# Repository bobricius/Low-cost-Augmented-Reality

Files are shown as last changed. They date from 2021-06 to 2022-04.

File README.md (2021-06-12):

# Low-cost-Augmented-Reality
Optimized for use microcontrollers and SPI displays popular ST7789 1.3" IPS 240x240 FEEL LIKE IRON MAN !!!!!

Something like Iron man helmet but can drive with simple arduino
Raspberry pi zero, PICO and more

- Driven with simple SPI interface
- Helmet cost about 30$ displays 10$
- 2x SPI IPS display 240x240 ST7789
- Easy drive with #samd21 #rp2040 #raspberrypi #ESP32
- no complicated HDMI
- beautiful and clear image in all you view
- LOW power about 60mA including SAMD21 MCU
- parallel or separated (for 3D) display driving
- USB OTG

YOU CAN TYPE ON KEYBOARD AND DIRECT READ MESSAGES :D

-module also have prepared LoRa radio for sending/receiving messages and GPS

TODO:
- Adjustable distance between displays (flex cable or solder bridge)
- Test on Raspbery pi zero
- select nice 8pin cable/connector etc. USB-C with custom pinout

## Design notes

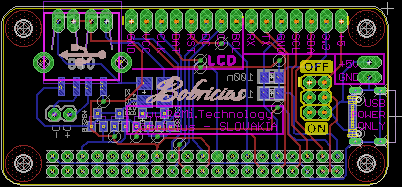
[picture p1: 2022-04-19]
pcb.png

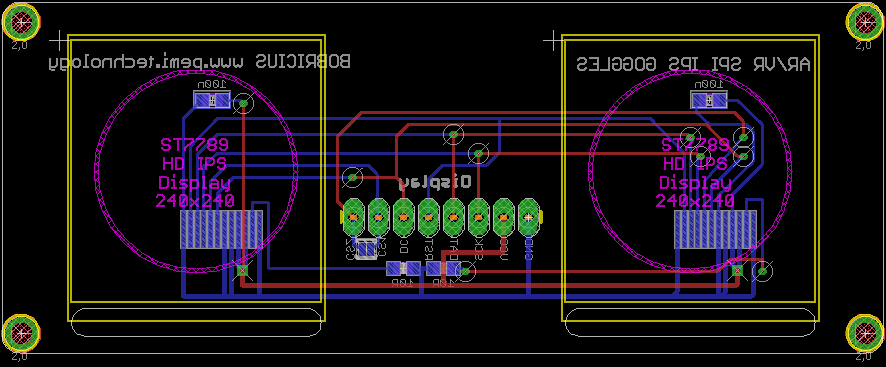
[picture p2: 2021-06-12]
board.png

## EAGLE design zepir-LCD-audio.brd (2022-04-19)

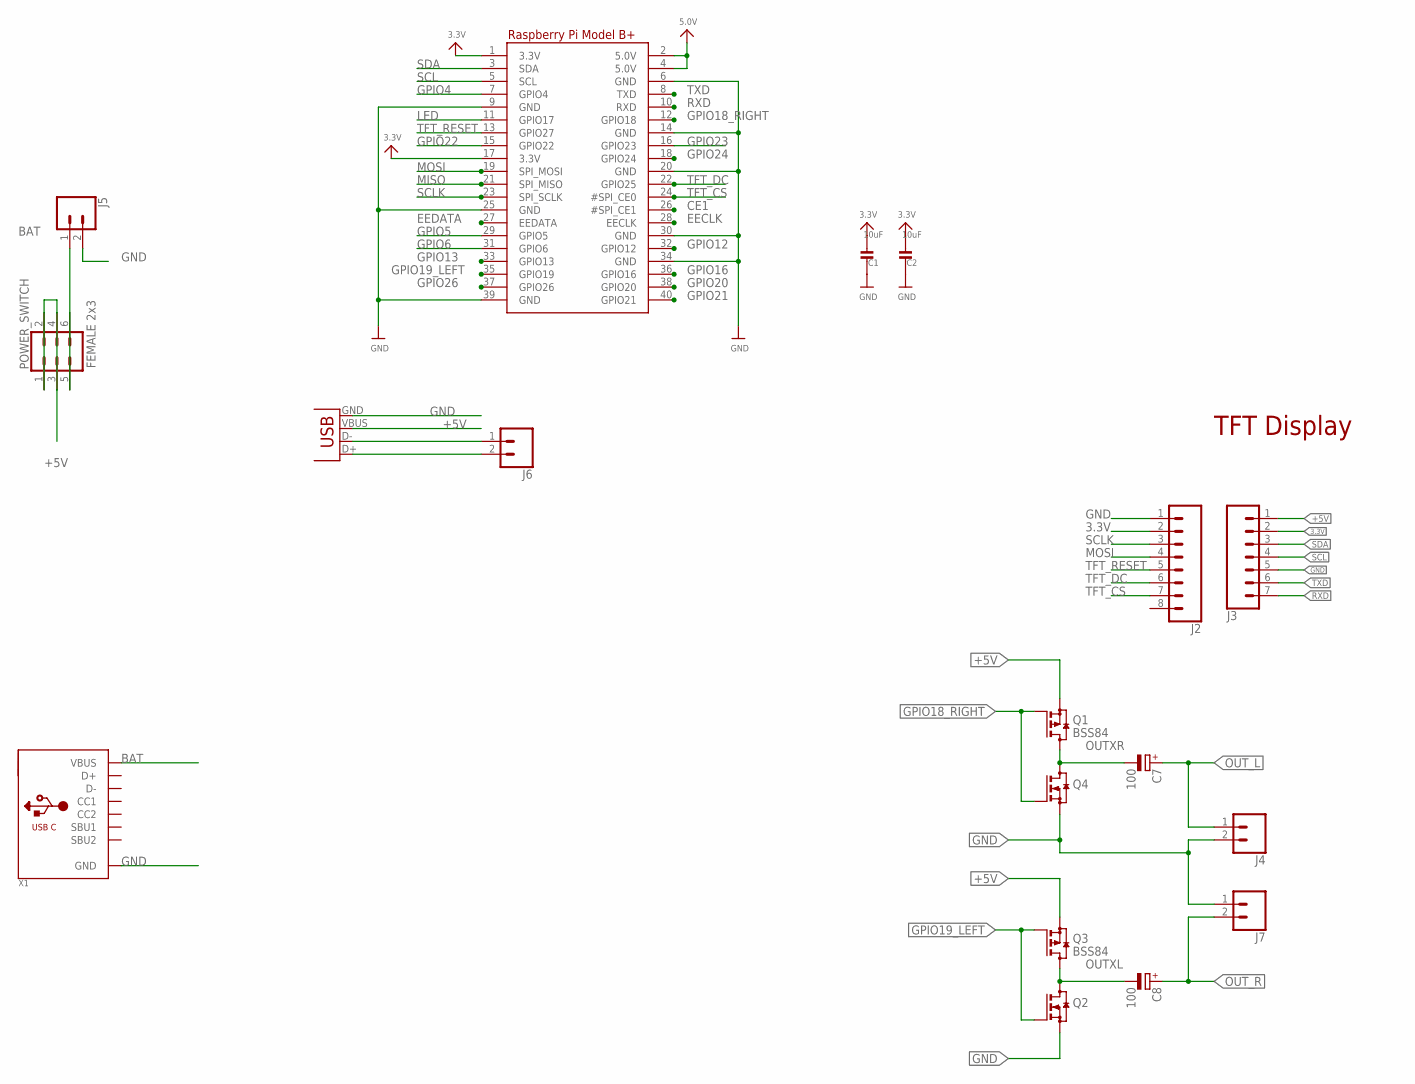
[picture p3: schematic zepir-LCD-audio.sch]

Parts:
C1, C2: 10uF; _1206
C7, C8: 100; B/3528-21R
J2: CONN_08LONGPADS; 1X08_LONGPADS
J3: CONN_07LONGPADS; 1X07_LONGPADS
J4, J5, J7: CONN_02PTH3; 1X02_LONGPADS
J6: CONN_02; 1X02
POWER_SWITCH: FEMALE 2x3; 2X3
Q1, Q3: BSS84; SOT23
Q2, Q4: BSS123; SOT23
RPI1: RASPBERRYPI_BPLUS_BONNETNODIM; PI_BONNET_NODIM
USBIN1: USB-A-SMD; USB-A-S-NOSILK-FEMALE
X1: USB_C; USB_C_CUSB31-CFM2AX-01-X

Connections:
3.3V: C1.2, C2.2, J2.2, J3.2, RPI1.1 (3.3V), RPI1.17 (3.3V)
+5V: J3.1, POWER_SWITCH.1, POWER_SWITCH.2, POWER_SWITCH.3, POWER_SWITCH.4, Q1.2 (S), Q3.2 (S), RPI1.2 (5.0V), RPI1.4 (5.0V), USBIN1.VBUS
BAT: J5.1, POWER_SWITCH.5, POWER_SWITCH.6, X1.A4B9 (VBUS), X1.B4A9 (VBUS)
CE1: RPI1.26 (#SPI_CE1)
DM: J6.1, USBIN1.D-
DP: J6.2, USBIN1.D+
EECLK: RPI1.28 (EECLK)
EEDATA: RPI1.27 (EEDATA)
GND: C1.1, C2.1, J2.1, J3.5, J4.2, J5.2, J7.1, Q2.2 (S), Q4.2 (S), RPI1.6 (GND), RPI1.9 (GND), RPI1.14 (GND), RPI1.20 (GND), RPI1.25 (GND), RPI1.30 (GND), RPI1.34 (GND), RPI1.39 (GND), USBIN1.GND, X1.A1B12 (GND), X1.B1A12 (GND)
GPIO4: RPI1.7 (GPIO4)
GPIO5: RPI1.29 (GPIO5)
GPIO6: RPI1.31 (GPIO6)
GPIO12: RPI1.32 (GPIO12)
GPIO13: RPI1.33 (GPIO13)
GPIO16: RPI1.36 (GPIO16)
GPIO18_RIGHT: Q1.1 (G), Q4.1 (G), RPI1.12 (GPIO18)
GPIO19_LEFT: Q2.1 (G), Q3.1 (G), RPI1.35 (GPIO19)
GPIO20: RPI1.38 (GPIO20)
GPIO21: RPI1.40 (GPIO21)
GPIO22: RPI1.15 (GPIO22)
GPIO23: RPI1.16 (GPIO23)
GPIO24: RPI1.18 (GPIO24)
GPIO26: RPI1.37 (GPIO26)
LED: RPI1.11 (GPIO17)
MISO: RPI1.21 (SPI_MISO)
MOSI: J2.4, RPI1.19 (SPI_MOSI)
OUTXL: C8.-, Q2.3 (D), Q3.3 (D)
OUTXR: C7.-, Q1.3 (D), Q4.3 (D)
OUT_L: C7.+, J4.1
OUT_R: C8.+, J7.2
RXD: J3.7, RPI1.10 (RXD)
SCL: J3.4, RPI1.5 (SCL)
SCLK: J2.3, RPI1.23 (SPI_SCLK)
SDA: J3.3, RPI1.3 (SDA)
TFT_CS: J2.7, RPI1.24 (#SPI_CE0)
TFT_DC: J2.6, RPI1.22 (GPIO25)
TFT_RESET: J2.5, RPI1.13 (GPIO27)
TXD: J3.6, RPI1.8 (TXD)

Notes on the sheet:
TFT Display

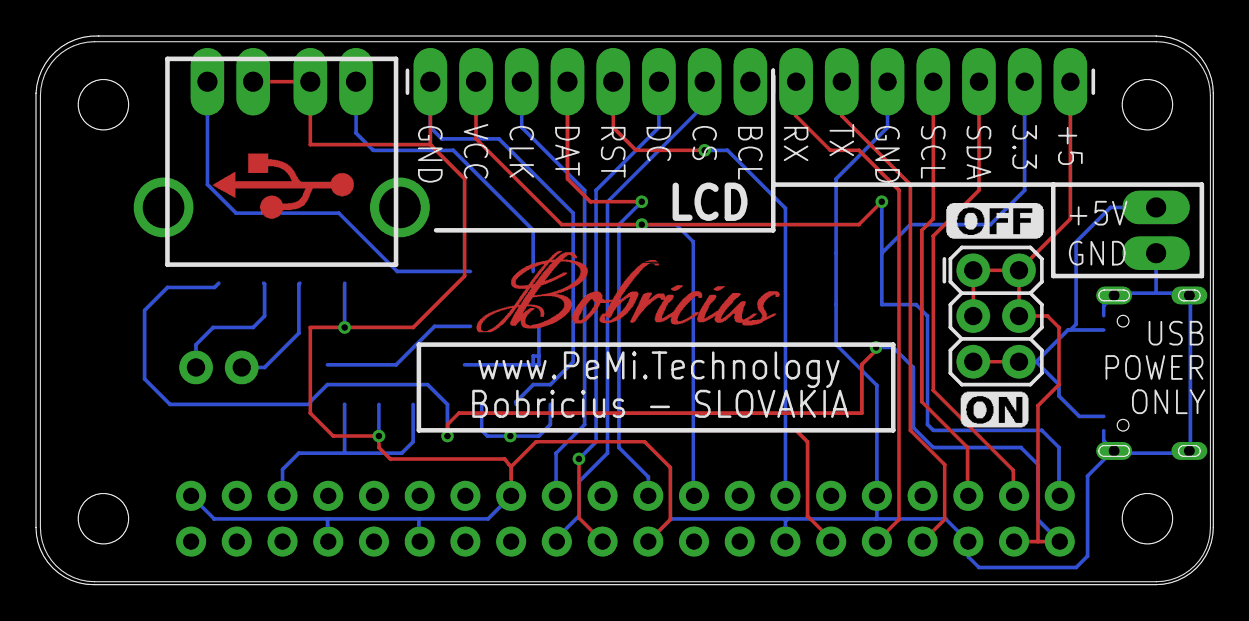
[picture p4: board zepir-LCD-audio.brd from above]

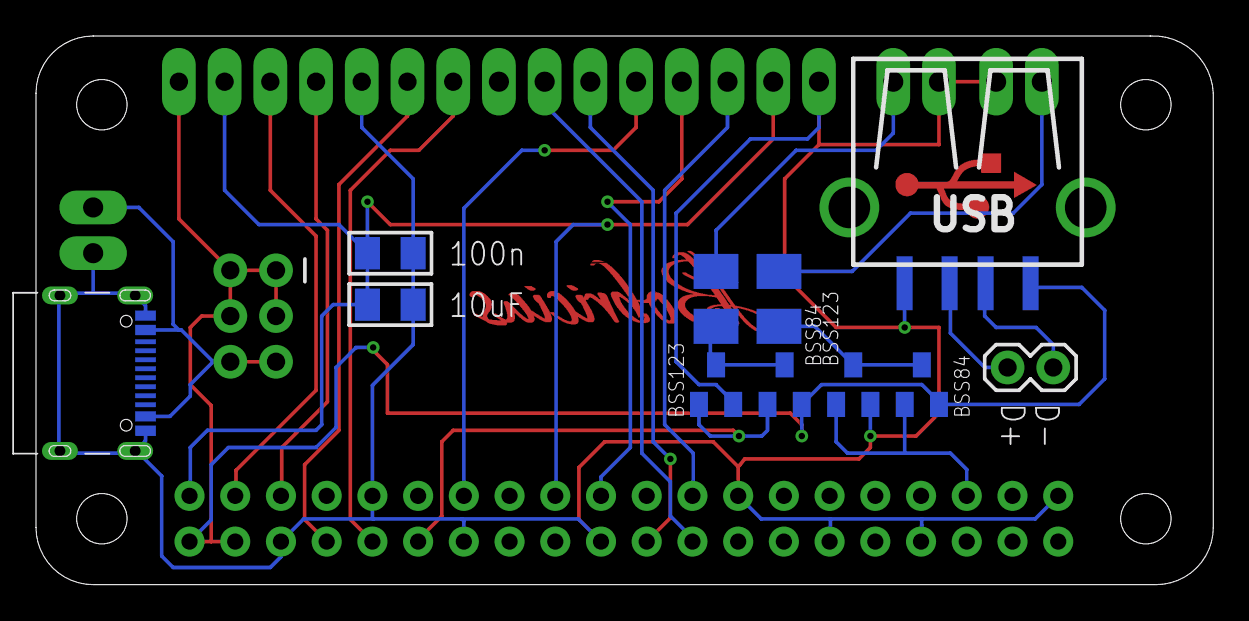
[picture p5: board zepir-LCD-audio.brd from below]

Board: 2 copper layers, 65.4 x 30.5 mm, 18 parts (11 on the bottom side), 21 nets.

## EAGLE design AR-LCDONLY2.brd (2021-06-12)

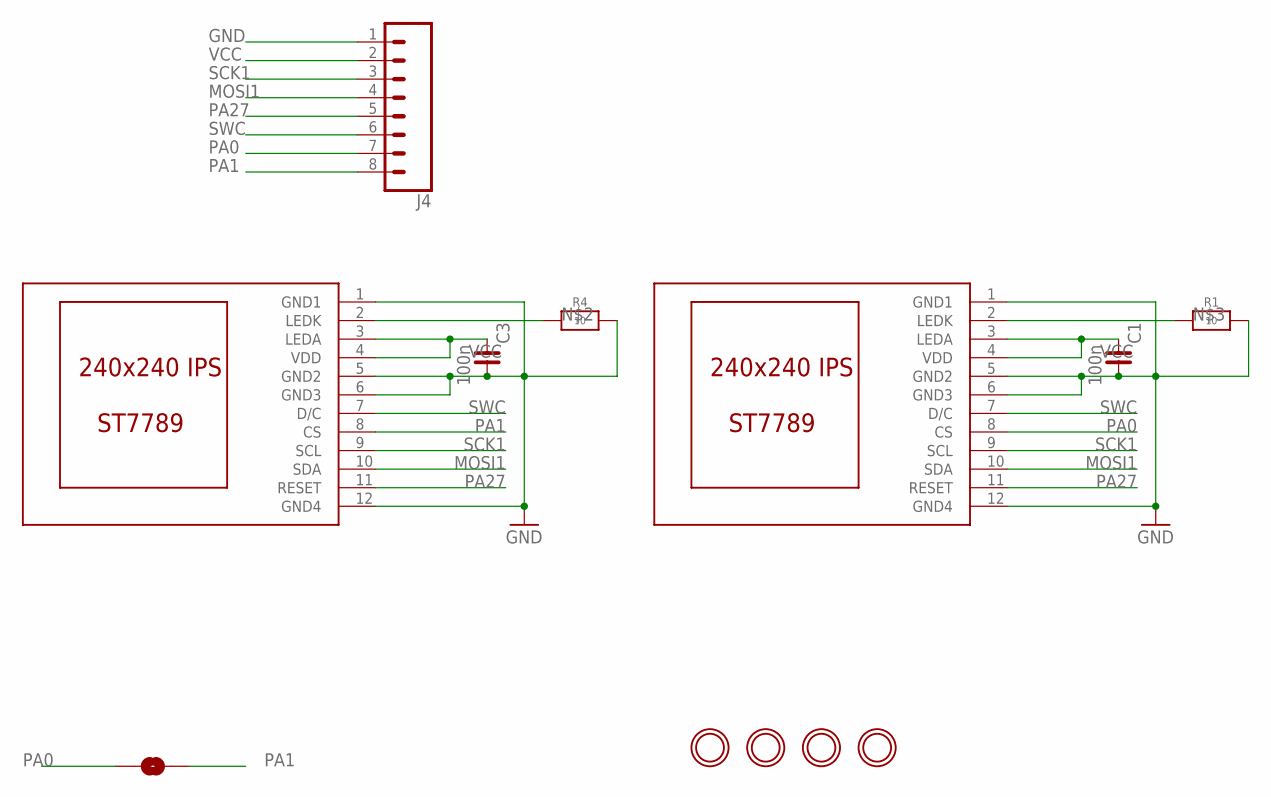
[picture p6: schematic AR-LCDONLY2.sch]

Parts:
C1, C3: 100n; C0805
J4: CONN_08LONGPADS; 1X08_LONGPADS
JUMPER1: SOLDERJUMPERNC2; SJ_2S-NOTRACE
R1, R4: 10; _0805MP
U$1, U$39: DISP_LCD_0.9IN_160X80; TFT_0.96IN_160X80
U$2, U$3, U$4, U$10: MOUNTINGHOLE2.0; MOUNTINGHOLE_2.0_PLATED

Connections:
GND: C1.1, C3.1, J4.1, R1.2, R4.2, U$1.1 (GND1), U$1.5 (GND2), U$1.6 (GND3), U$1.12 (GND4), U$39.1 (GND1), U$39.5 (GND2), U$39.6 (GND3), U$39.12 (GND4)
MOSI1: J4.4, U$1.10 (SDA), U$39.10 (SDA)
unnamed: R4.1, U$39.2 (LEDK)
unnamed: R1.1, U$1.2 (LEDK)
PA0: J4.7, JUMPER1.2, U$1.8 (CS)
PA1: J4.8, JUMPER1.1, U$39.8 (CS)
PA27: J4.5, U$1.11 (RESET), U$39.11 (RESET)
SCK1: J4.3, U$1.9 (SCL), U$39.9 (SCL)
SWC: J4.6, U$1.7 (D/C), U$39.7 (D/C)
VCC: C1.2, C3.2, J4.2, U$1.3 (LEDA), U$1.4 (VDD), U$39.3 (LEDA), U$39.4 (VDD)

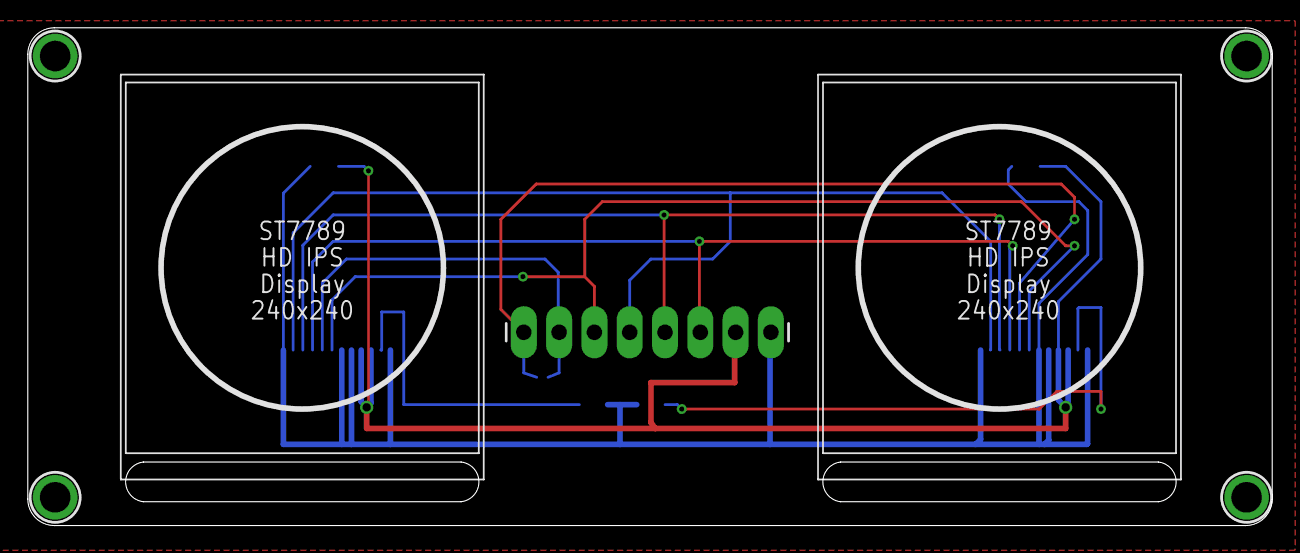
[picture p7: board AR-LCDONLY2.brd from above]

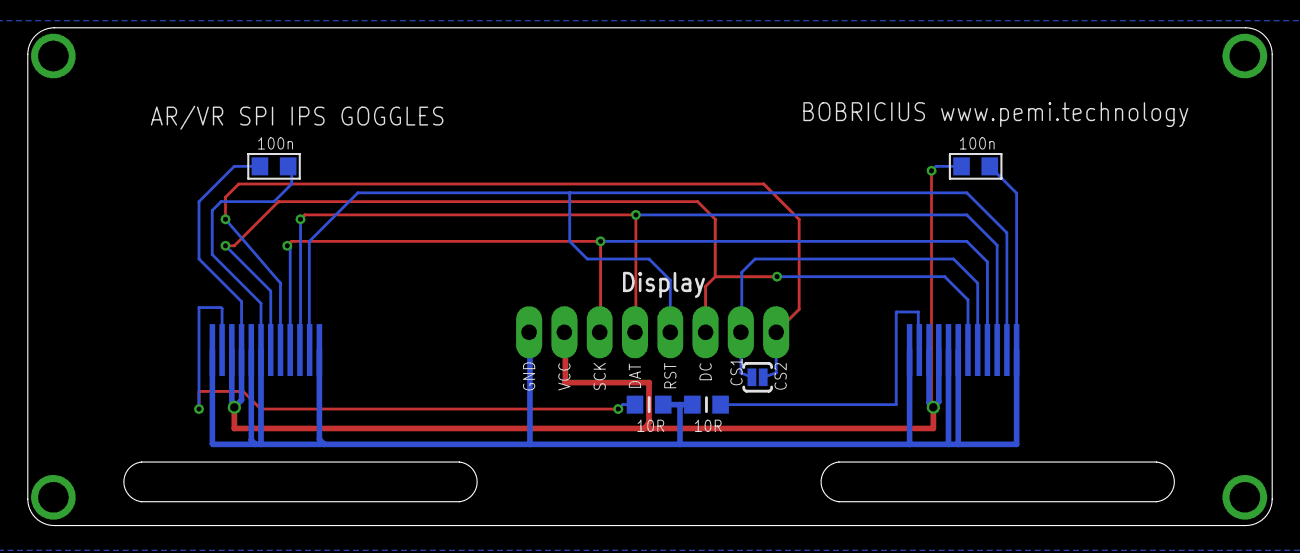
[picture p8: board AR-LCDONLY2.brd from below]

Board: 2 copper layers, 89.5 x 35.8 mm, 12 parts (5 on the bottom side), 10 nets.

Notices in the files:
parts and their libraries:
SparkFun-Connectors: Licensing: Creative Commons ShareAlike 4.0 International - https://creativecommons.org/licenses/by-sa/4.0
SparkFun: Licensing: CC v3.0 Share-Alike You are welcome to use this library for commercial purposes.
